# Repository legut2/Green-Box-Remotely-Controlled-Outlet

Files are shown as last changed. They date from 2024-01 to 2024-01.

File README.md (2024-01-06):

# Green Box: Remotely Controlled Outlet(s) to Reduce Electricity Consumption and Monitor Equipment
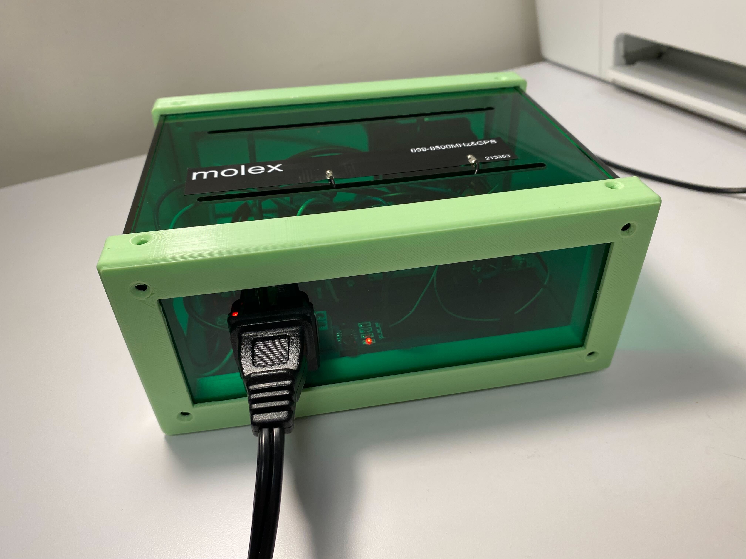
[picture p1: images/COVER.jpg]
cover photo of greenbox Green Box

# Intro
In a world where customers and investors increasingly support environmentally friendly products and services, distinguishing a genuine eco-conscious company from greenwashers is challenging. Many organizations strive to be recognized for their minimal environmental impact, with some genuinely caring for the environment. The greenbox concept caters to these environmentally conscious companies. It's crucial to acknowledge that people often forget to turn off devices, leading to unnecessary energy consumption. Most companies depend on well-trained employees to remember to switch off equipment, a method that lacks sustainability and transparency.  '
  
Personally, I often joke that I'm a one-man ecological disaster due to my environmentally harmful habits, such as not recycling and using disposable plates and cups excessively. Despite this, I consider myself environmentally aware. My individual environmental footprint may be small, but my professional decisions can significantly impact the environment. To compensate for my subpar personal environmental practices, I propose an idea to help companies reduce power consumption. This involves remotely monitoring and deactivating outlets that consume power unnecessarily, a step towards more responsible energy use in the workplace.

# Materials and Supplies
- [Blues Global Starter Kit](https://shop.blues.com/products/blues-global-starter-kit)
- [One Channel 5V Relay](https://www.amazon.com/gp/product/B00LW15A4W/ref=ox_sc_saved_title_2?smid=A30QSGOJR8LMXA&psc=1)
- [Wired Outlet Plug](https://www.amazon.com/gp/product/B092VQNKN7/ref=ox_sc_saved_image_3?smid=AOTJB6UAIIPDH&psc=1)
- [Fused Power Socket with Rocker Switch](https://www.amazon.com/gp/product/B07Y8DBF7T/ref=ox_sc_saved_title_6?smid=A1ZS0R4YE7AG81&psc=1)
- [AC to DC 5V Power Supply](https://www.amazon.com/gp/product/B07V5XP92F/ref=ppx_yo_dt_b_search_asin_title?ie=UTF8&psc=1)
- [Power Cord](https://www.amazon.com/gp/product/B000067SLV/ref=ox_sc_saved_title_4?smid=ATVPDKIKX0DER&psc=1)
- [ACS712 Current Sensor](https://www.amazon.com/gp/product/B00XT0PL20/ref=ox_sc_saved_title_7?smid=A30Y6WWS77DGEW&th=1)
- [1/8 inch (3mm) Acrylic 5 Sheets](https://www.amazon.com/gp/product/B0BN17KVV5/ref=ppx_yo_dt_b_search_asin_title?ie=UTF8&th=1)
- 3D Printing Filament PLA
- [wires](https://www.amazon.com/gp/product/B089CXJPSC/ref=ppx_yo_dt_b_search_asin_title?ie=UTF8&th=1), [wires](https://www.amazon.com/gp/product/B089D13Y1N/ref=ppx_yo_dt_b_search_asin_title?ie=UTF8&th=1), [wires](https://www.amazon.com/gp/product/B083352WFF/ref=ppx_yo_dt_b_search_asin_title?ie=UTF8&psc=1), and more [wires](https://www.amazon.com/gp/product/B07GD2BWPY/ref=ppx_yo_dt_b_search_asin_title?ie=UTF8&th=1)
- [Soldering Flux](https://www.amazon.com/gp/product/B008ZIV85A/ref=ppx_yo_dt_b_search_asin_title?ie=UTF8&th=1)
- [M3 Nylon Fasteners](https://www.amazon.com/gp/product/B076J5RGKS/ref=ppx_yo_dt_b_search_asin_title?ie=UTF8&th=1), [M3 Nylon Standoffs](https://www.amazon.com/gp/product/B0B2MPSH6T/ref=ppx_yo_dt_b_search_asin_title?ie=UTF8&th=1), and more [M3 Nylon Fasteners](https://www.amazon.com/gp/product/B071XPTK7Z/ref=ppx_yo_dt_b_search_asin_title?ie=UTF8&psc=1) because Nylon doesn't conduct electricity well at all.
- [Super Glue](https://www.amazon.com/Starbond-Cyanoacrylate-Microtips-Woodturning-Stabilizing/dp/B00C32ME6G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)
- [USB-A to Micro USB type B](https://www.amazon.com/Amazon-Basics-Charging-Transfer-Gold-Plated/dp/B0711PVX6Z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) to flash board
- [Cotton balls](https://www.amazon.com/Amazon-Basics-Cotton-Balls-200ct/dp/B09497R2CN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) for cleaning burn marks on cut panels
- [Cotton Swabs](https://www.amazon.com/Amazon-Basics-Cotton-Swabs-500ct/dp/B09541P9WH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) for cleaning burn marks on cut panels
- [Rubbing Alcohol](https://www.amazon.com/Amazon-Brand-Rubbing-Alcohol-Antiseptic/dp/B07RB7XYQ1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) for cleaning tooling marks
# Tools
- [Helping Hands](https://www.amazon.com/gp/product/B08R5CDSX4/ref=ppx_yo_dt_b_search_asin_title?ie=UTF8&psc=1) for holding wires and parts while soldering
- [Wire Strippers](https://www.amazon.com/gp/product/B000JNNWQ2/ref=ppx_yo_dt_b_search_asin_title?ie=UTF8&th=1)
- [Wire Wrap Tool](https://www.amazon.com/gp/product/B00C9NWR1Q/ref=ppx_yo_dt_b_search_asin_title?ie=UTF8&psc=1) for a quick way to alternatively attach wires
- [Portable Soldering Iron](https://www.amazon.com/gp/product/B071K5FNGT/ref=ppx_yo_dt_b_search_asin_title?ie=UTF8&th=1)
- [Dremel 3D40 Printer](https://fox.build/equipment/dremel-3d40-printer/)
- [Laser Cutter](https://fox.build/equipment/big-blue-laser/)
- [X-ACTO Knife](https://www.amazon.com/X-ACTO-Yourself-Great-Arts-Crafts/dp/B000HGMA7I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) and/or [Clay Shaping Tools](https://www.amazon.com/TEACHERS-Pottery-Sculpting-Double-Sided-Handles/dp/B08KD22B4Y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) for cleaning up 3D print
# Software Tools
- [Arduino](https://www.arduino.cc/en/software)
- [VSCode](https://code.visualstudio.com/)
- [Notehub](https://notehub.io)
- [Python 3.10.0](https://www.python.org/downloads/release/python-3100/)
# Schematic
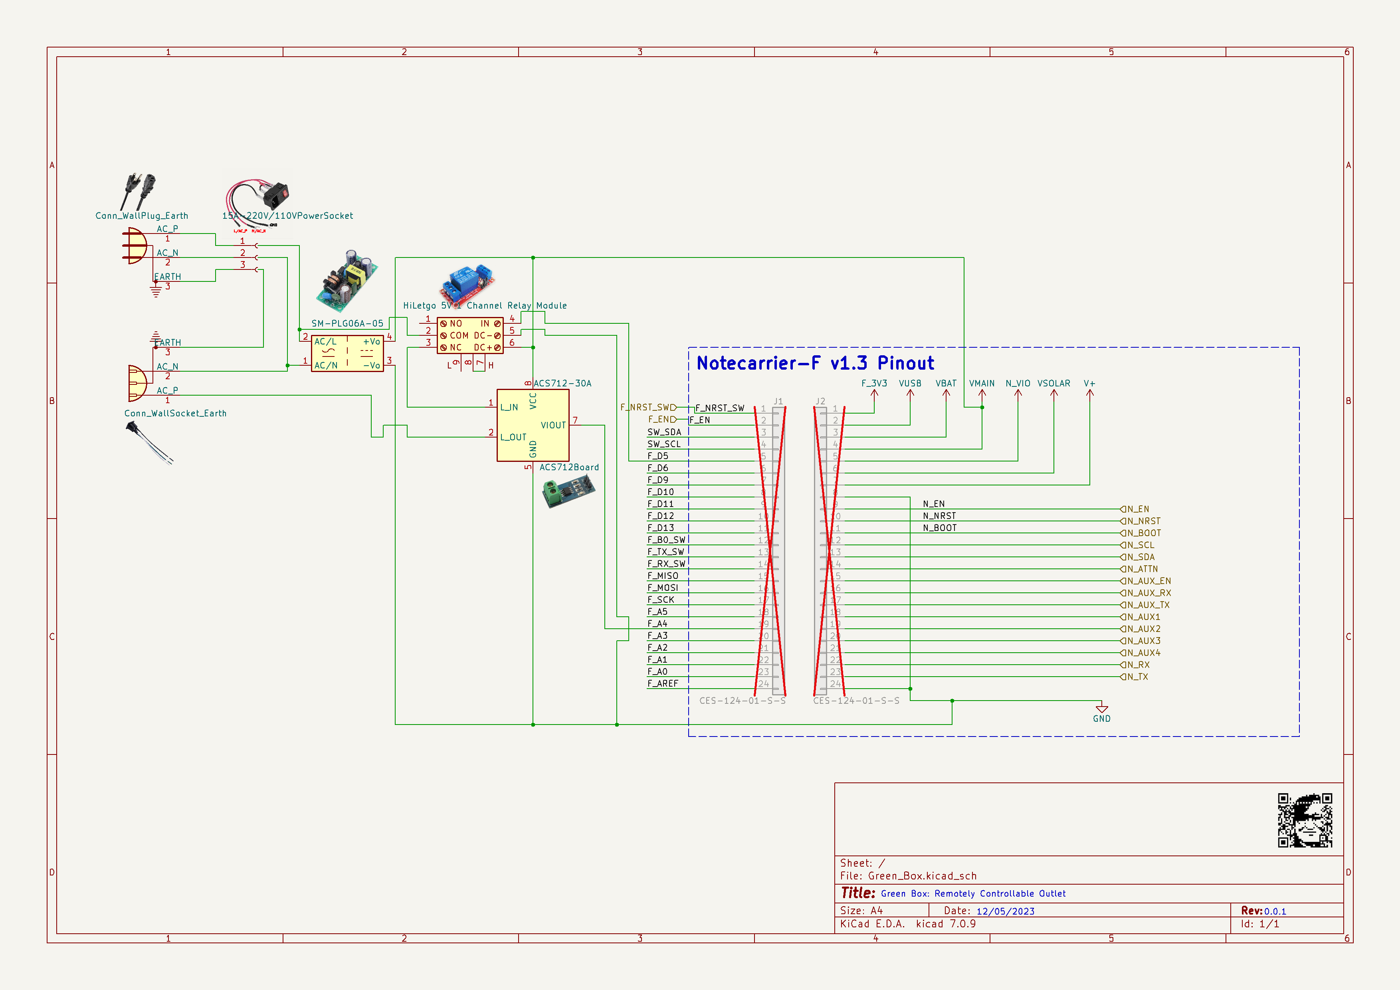
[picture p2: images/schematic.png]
schematic of greenbox Schematic
  
[KiCAD Zipped Files](./Green_Box_KiCAD.zip)  
# CAD
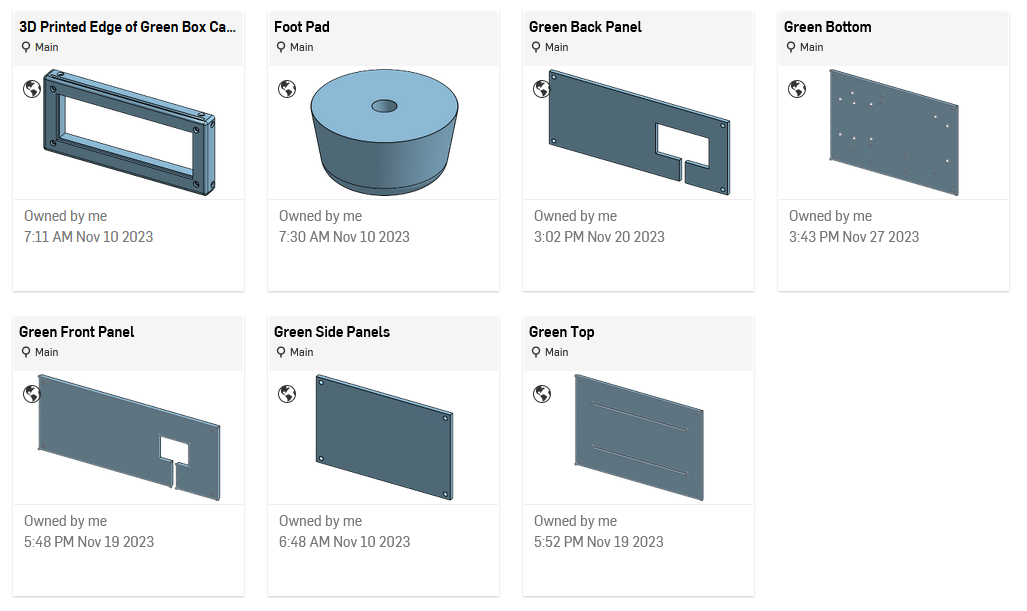
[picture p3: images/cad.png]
CAD Models of Box Parts

- [3D Printed Edges](https://cad.onshape.com/documents/768bf325ce61f204b1c20e3a/w/13f10a06ca5bd000585b50f8/e/0a809bd2397b4e0a646dd88c) [(STL File)](./CAD/3D%20Printed%20Edge.stl)
- [Bottom Panel](https://cad.onshape.com/documents/b0d329d86337c70760adce23/w/ca1183aaf425e30395dbaaf4/e/549da84961c1aeb2ba495f54) [(DXF File)](./CAD/Green%20Bottom.dxf)
- [Front Panel](https://cad.onshape.com/documents/e55aef7daf51d2362b13b44b/w/da2b1076433f546c797e1f83/e/66cb452b38848d0268798330) [(DXF File)](./CAD/Front%20Panel.dxf)
- [Back Panel](https://cad.onshape.com/documents/593eb36193b087ff43dc2f72/w/bbb9e1fdf7dfe1317e187362/e/3f4225e0dbdc0654de7b20f0) [(DXF File)](./CAD/Back%20Panel.dxf)
- [Side Panel](https://cad.onshape.com/documents/a36065bf40c209600cc4383d/w/08a4eee43424d48ec8693589/e/5a183de64443f7edcd656746) [(DXF File)](./CAD/Side%20Panel.dxf)
- [Top Panel](https://cad.onshape.com/documents/84086fb6dc831c0922238dac/w/1929451043a0cdd72cf4c331/e/d913d1e3925c53207bd2e979) [(DXF File)](./CAD/Top%20Panel.dxf)
- [Foot Pad](https://cad.onshape.com/documents/e05155efe7ebecf075a4ab0f/w/05d481c3344dacce6687c214/e/0d07fca45d25f3ce5d8b2458) [(STL File)](./CAD/Foot%20Pad.stl)
# Guide
### Start with Printing Edges and Cutting Panels
For me, it's really frustrating when hardware moves around and isn't secure. It makes troubleshooting much more difficult if electronics are moving and aren't mounted firmly in place. So we're going to start by 3D printing the edges and laser cutting the panels. So open whatever compatible slicer software you have and prepare your print file for printing. Please know that the image below is representative and isn't ultimately the print file I ended up using.
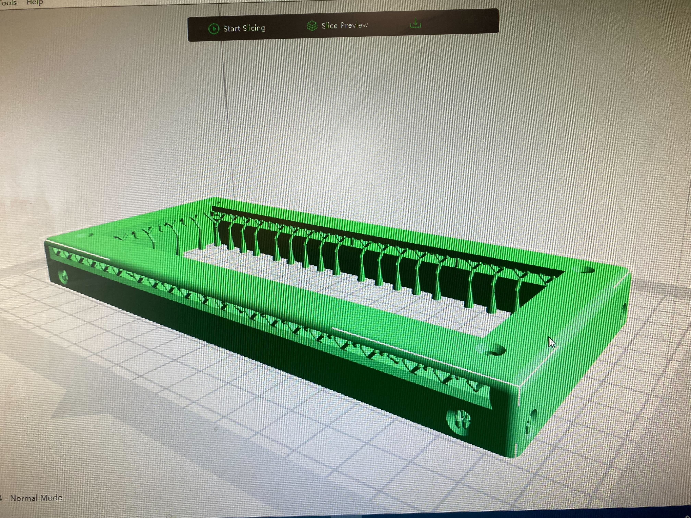
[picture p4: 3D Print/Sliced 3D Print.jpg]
3D model

Here you can find the [3D Print gcode I used](./3D%20Print/Green%20Box%20Enclosure%20Edge.gcode), but results may vary because you may have a different printer than the one I used. However, looking at the supports I used may be very useful. It took quite a lot of trial and error to get the supports right, and you want to avoid any layer shifts to have panel fit easily. You'll want to print 2 of these edges.
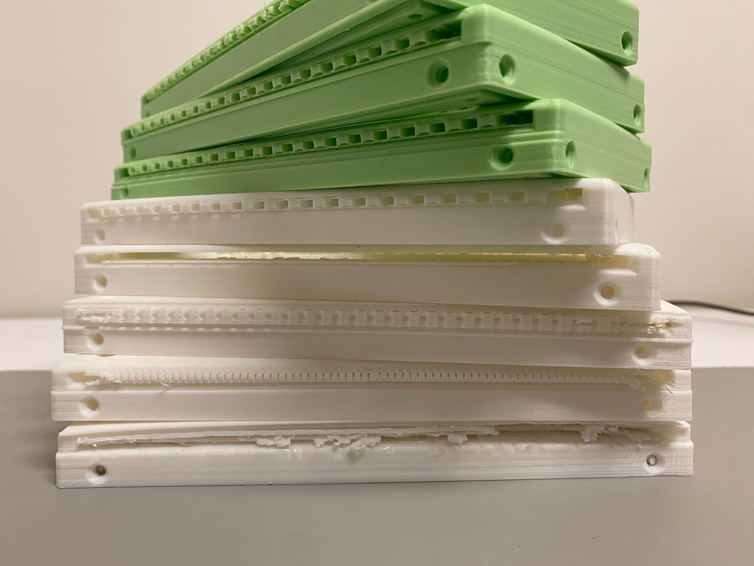
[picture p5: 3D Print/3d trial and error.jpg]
Trial and Error to get supports and layer shifting correct

Next you want to use the dxf files and load them into your laser cutting software and verify correct units within the software. Then utilize 70% power and 5.5mm/s jogging speed to cut the acrylic panels. Depending on how much wear and the wattage of the laser you use, you may have to use different settings used to cut through the acrylic sheets. Cut out the bottom, 2 sides, top, front, and back panel. Given the tedious nature of 3D printing, it is really nice to be able to laser cut parts for any design changes. This is especially true for prototyping. There is time saved on small changes where you don't have to wait as long for a machine to run to make you a part.
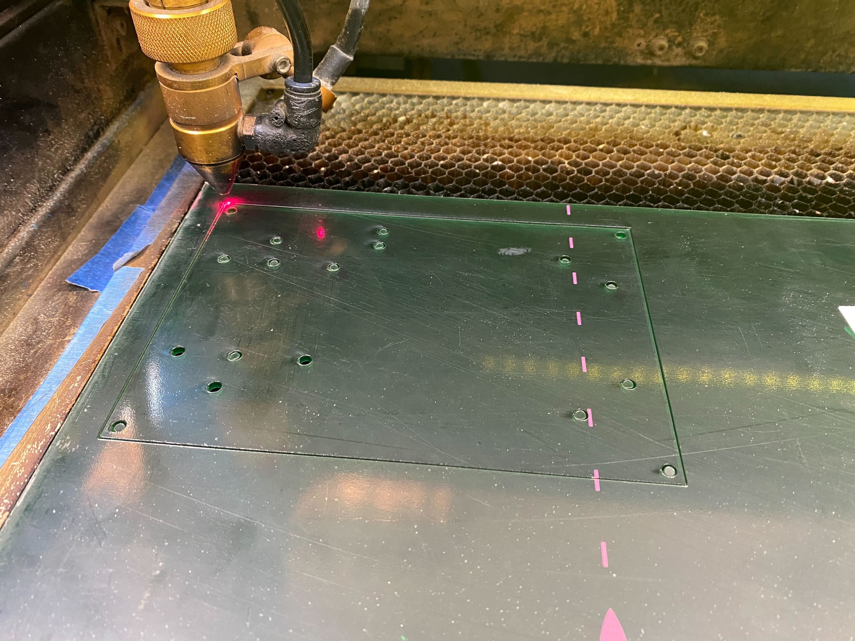
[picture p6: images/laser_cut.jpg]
Laser Cutting Bottom Panel

Next you'll notice there are burn marks left over from the laser cutting through.
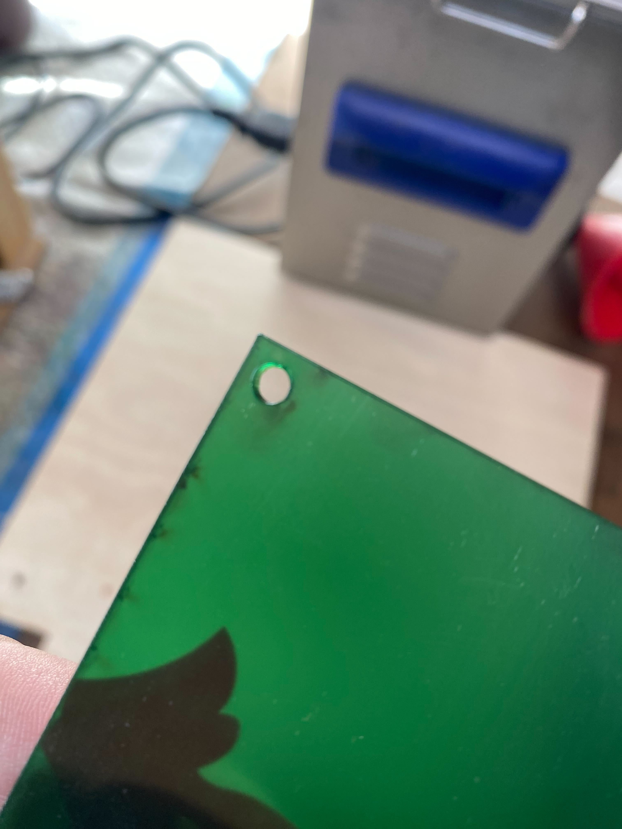
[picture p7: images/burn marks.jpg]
Tooling Marks from Laser Cutter

You'll want to use rubbing alcohol to clean that up.
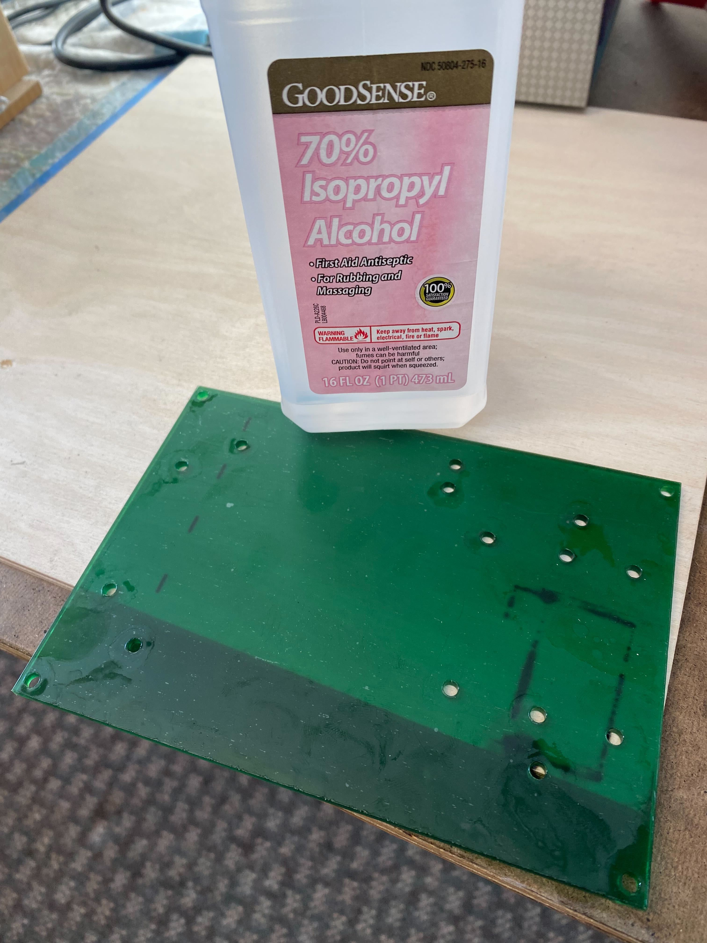
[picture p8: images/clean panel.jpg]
Rubbing Alcohol

That's much better!
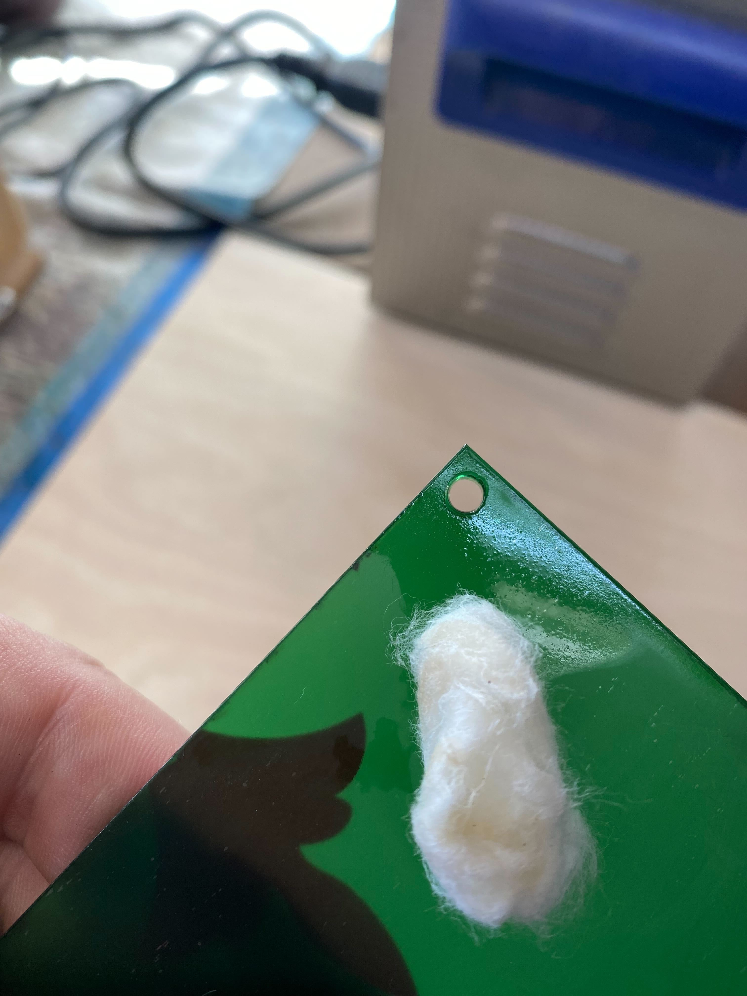
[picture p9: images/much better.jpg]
Cleaned up edges of each panel

Also, you'll want to spend time using an X-ACTO knife and other sharp tools, like from a clay sculpting kit to clean off any supports from your 3D prints.
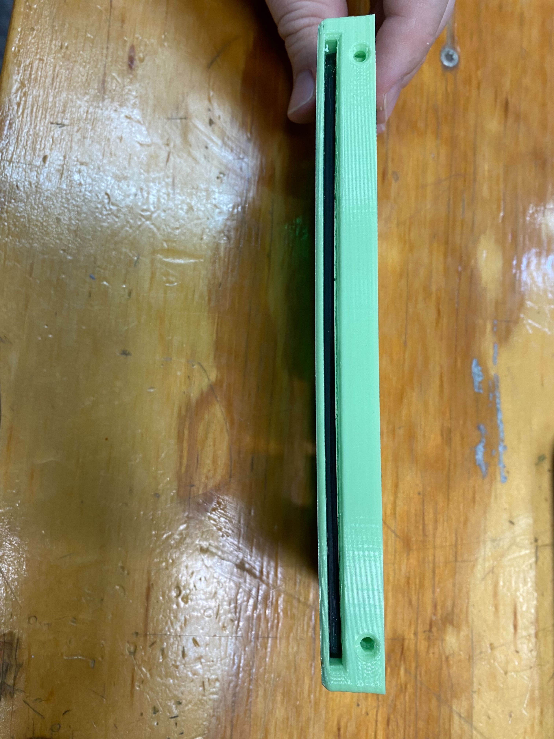
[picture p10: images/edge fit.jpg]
Cleaned up 3D Print

The edge should be able to cleanly fit one of the front of back panels, and use them to gauge how cleaned up the edge parts are for the box.
### Test Fit Panels and Edges
Next you'll want to test fit parts together to make sure they all go together nicely.
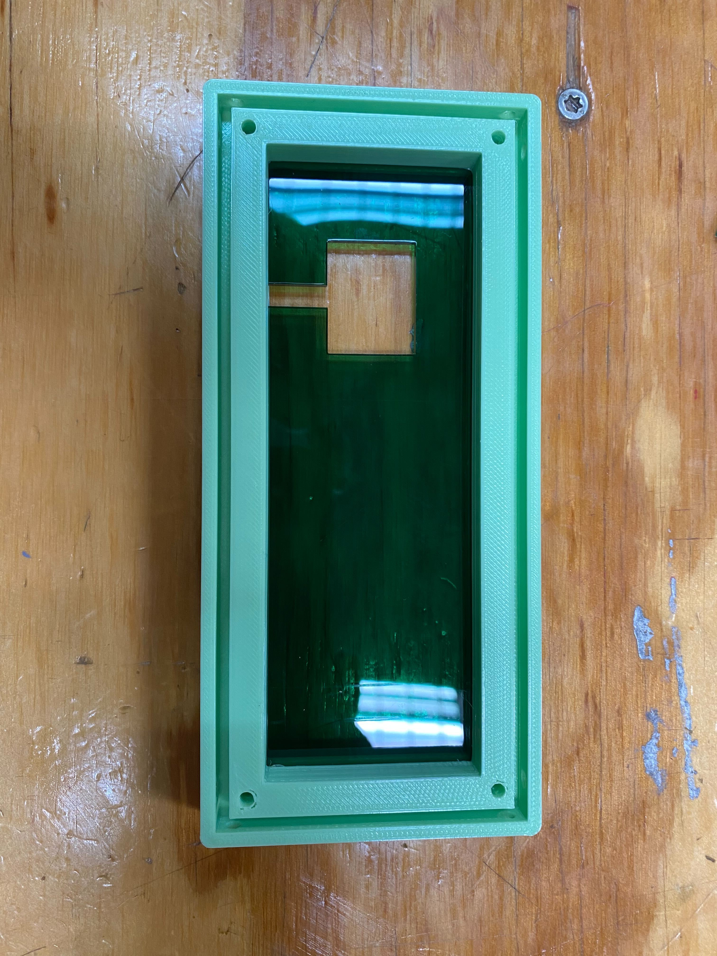
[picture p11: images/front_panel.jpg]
front panel and edge piece put together

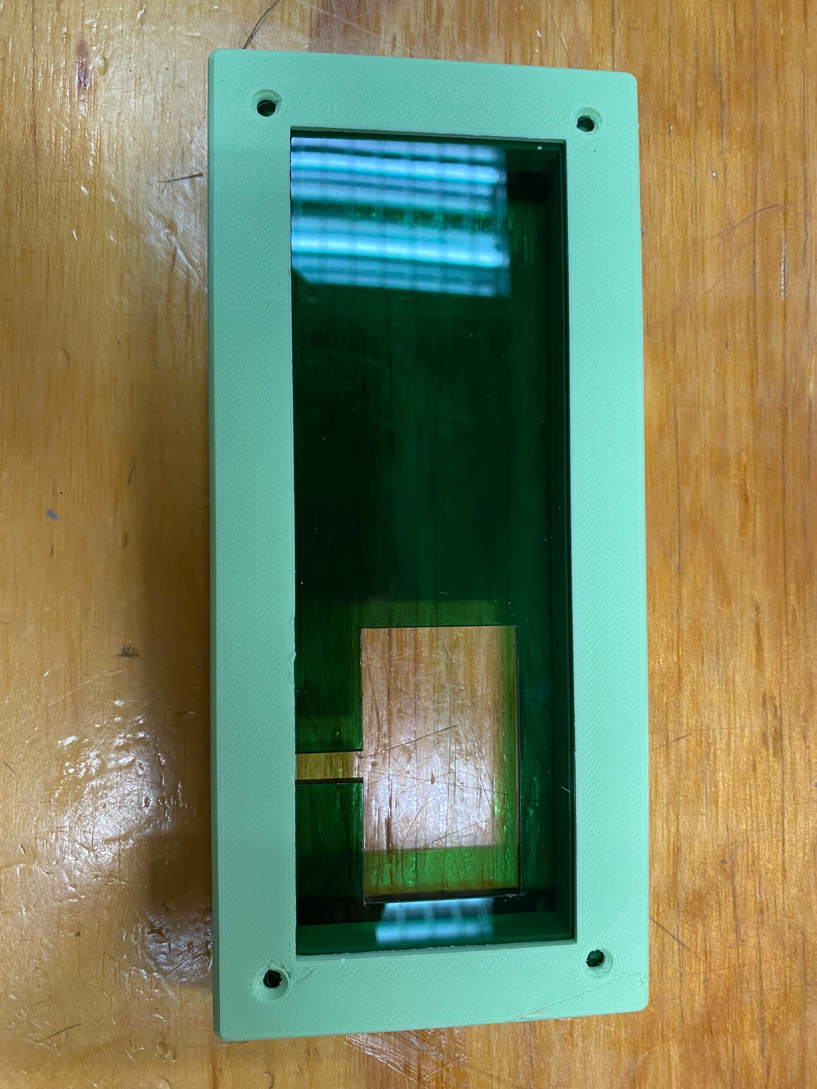
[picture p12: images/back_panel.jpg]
back panel and edge piece put together

Now you will want to make verify that the front plug fits correctly.
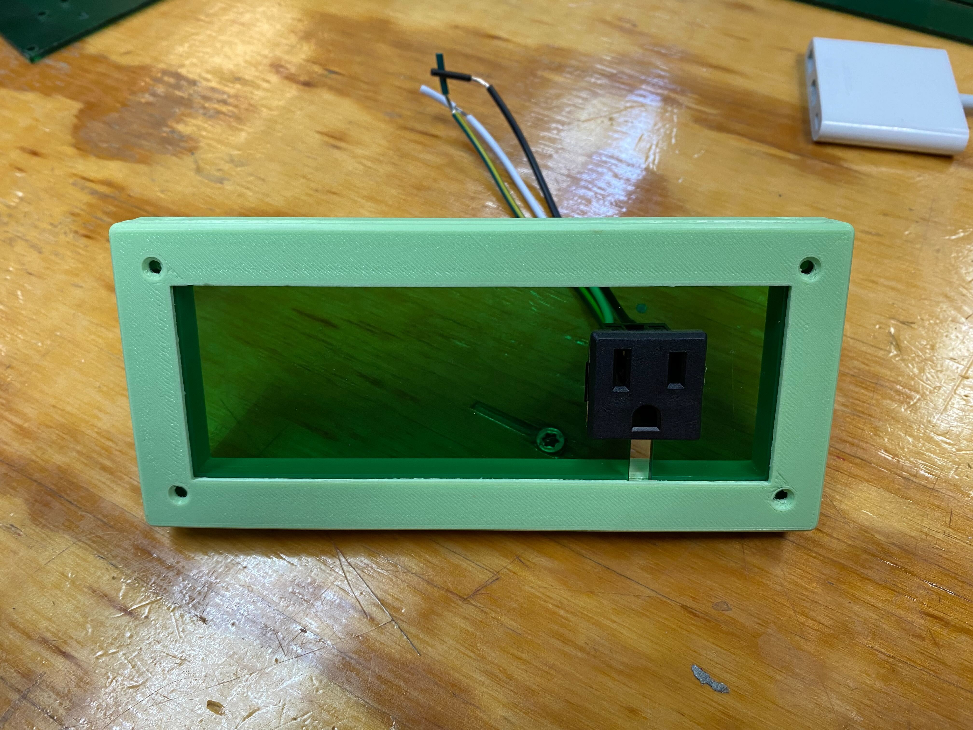
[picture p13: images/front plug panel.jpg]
front plug test fitted into panel

You will want to trim the tabs on the fused power socket to make sure they fit and snap into place.
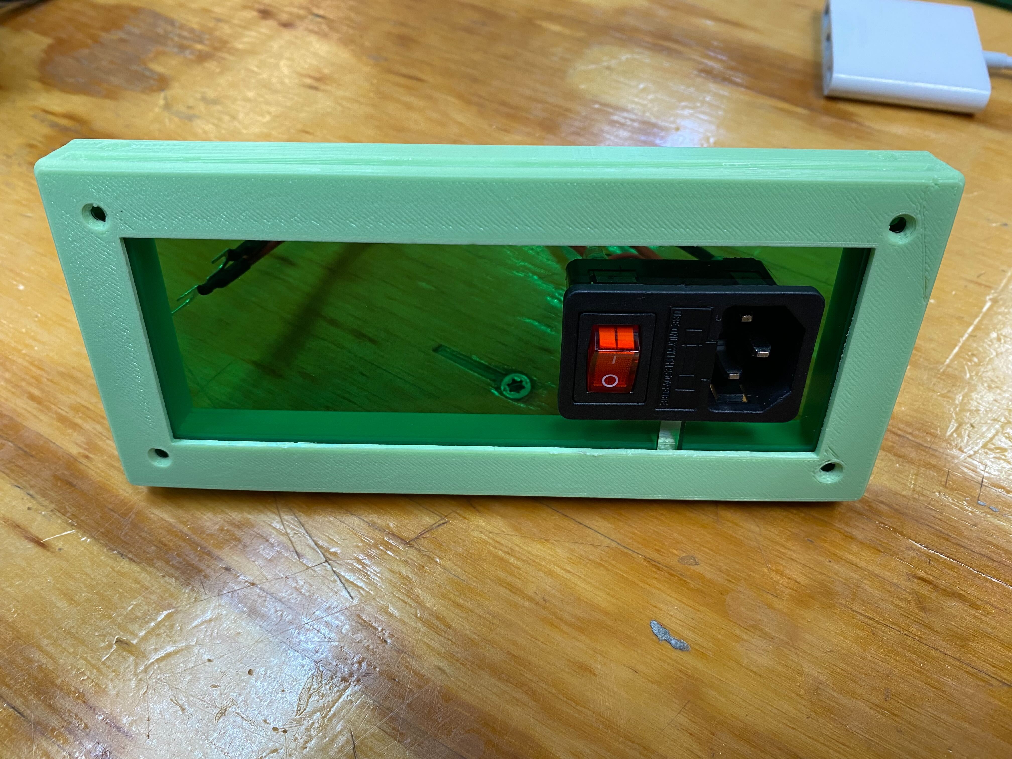
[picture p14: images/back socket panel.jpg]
back socket panel test fit

Now you'll want to make sure panels fit together snuggly like the bottom, sides, and top slide easily together and apart.
### Mount Electronics
Now mount the blues wireless board by using M3 standoffs and M3 fasteners together onto the bottom panel. One of the benefits, that isn’t immediately obvious, is that this board has a dedicated data service that comes with it. This is really useful when you realize how many customer calls this can avoid troubleshooting connectivity problems. A surprisingly good number of IT departments are weary of the IoT devices that get setup within the workplace. If we are to hope for any widespread adoption of such a concept, it’s best for it to be on a separate network to make it easy for IT departments to approve it for use.
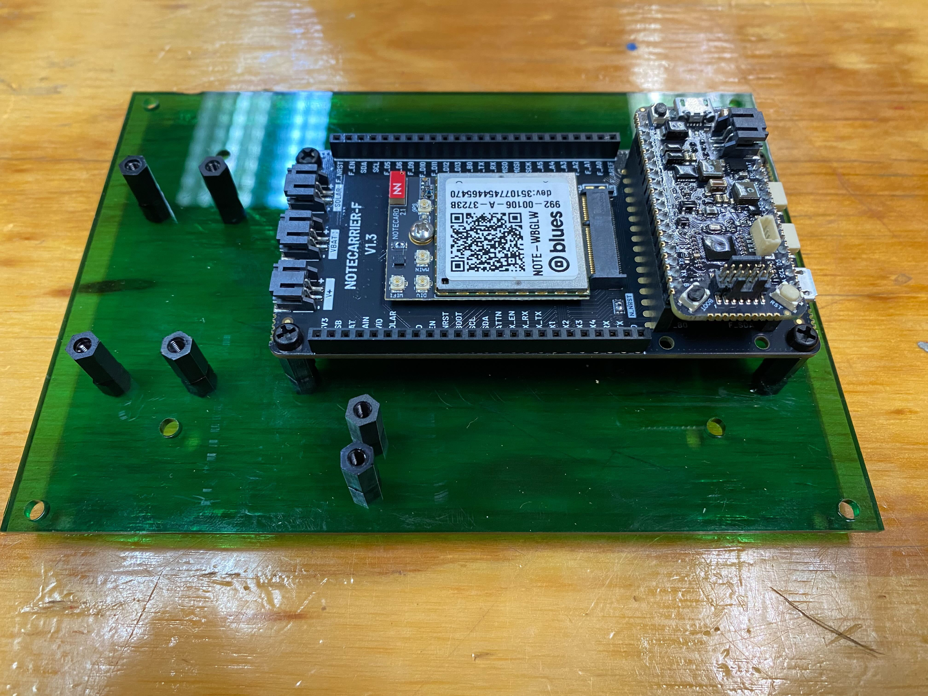
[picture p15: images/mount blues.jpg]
mount blues board

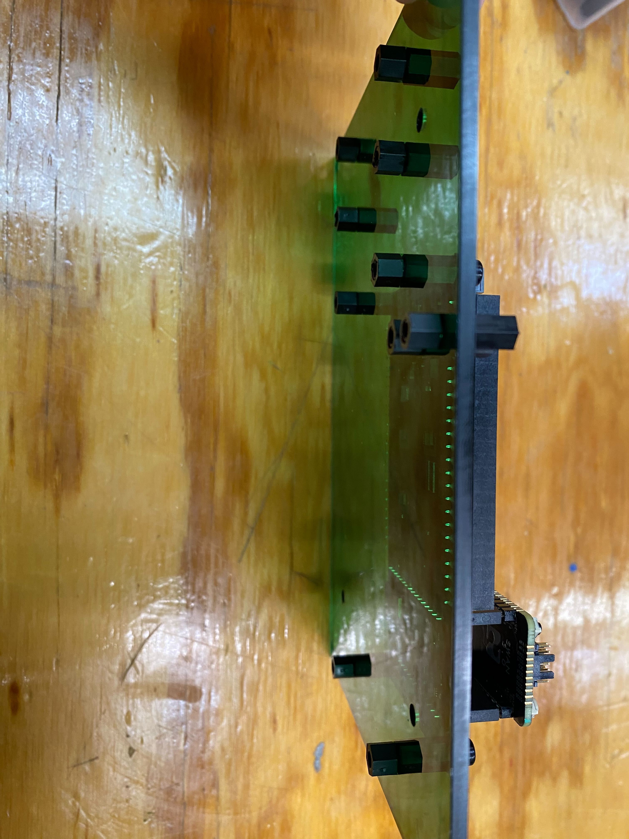
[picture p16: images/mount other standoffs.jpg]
mount standoffs for other parts too

Mount the relay, ACS712 current sensor, and the AC to DC power supply.
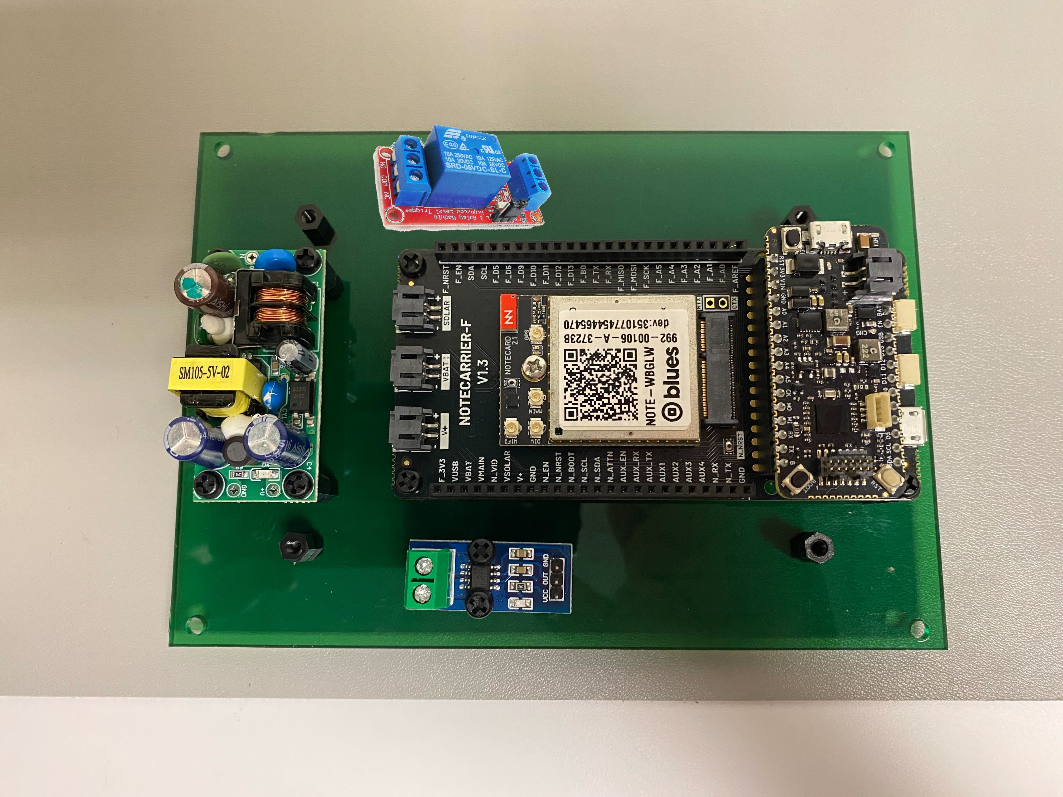
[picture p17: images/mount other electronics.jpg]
mount other electronics

At this point I decided to permanently glue the bottom panel to each edge using super glue, but that is a somewhat irreversible decision. You can also choose to temporarily fasten the bottom panel together. I just kept sliding panels in and out of place by flexing the bottom panel slightly. However, this might not work for everyone because if you use too much force you can crack the bottom panel. So I recommend most people use fasteners.

This clamshell configuration of the case is immensely useful for easily soldering and being able to reach hands into the case from the sides.
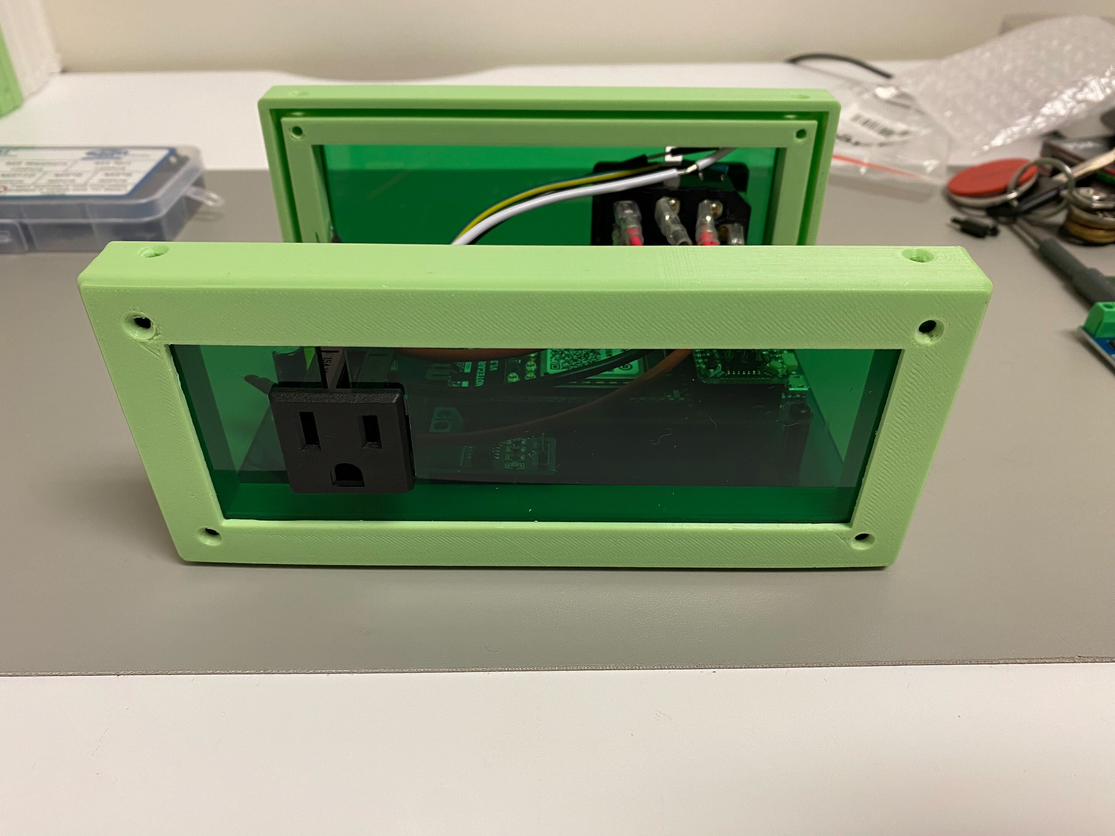
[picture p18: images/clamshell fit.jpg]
clamshell fit of the box

### Wire Electronics together
Solder the electronics together according to the schematic, starting with the internal components that are mounted and working your way outward to the plug and socket on the front and back panel.
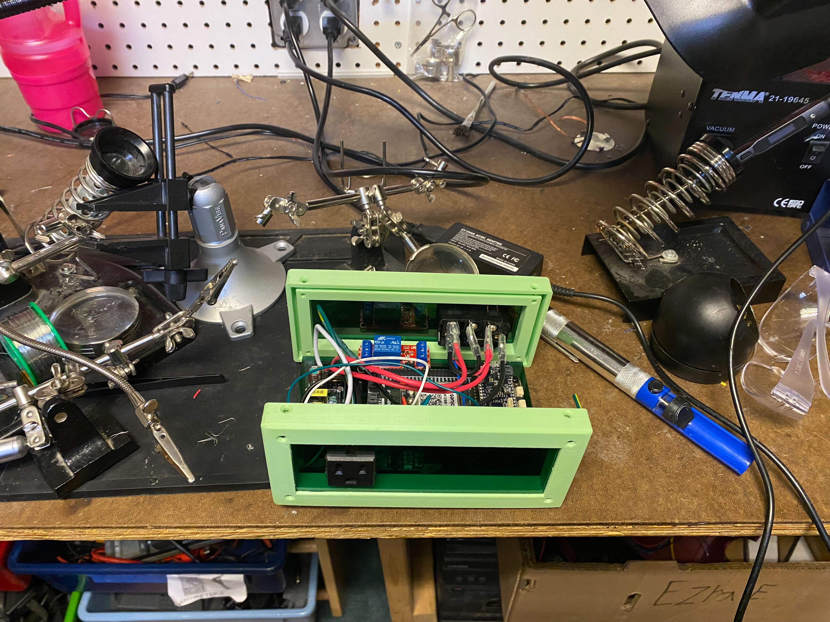
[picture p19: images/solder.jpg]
solder electronics together

It would probably be best to download the [KiCAD schematic](./Green_Box_KiCAD.zip) and be able to zoom in and out on the wiring. In hindsight, I'd recommend desoldering the headers on the blues wireless board for a more secure connection. I had to resort to using jumper wires and wirewrapping some of the ends to make some of the connections.
You'll also want to carefully add the antenna once you're certain of the wiring.
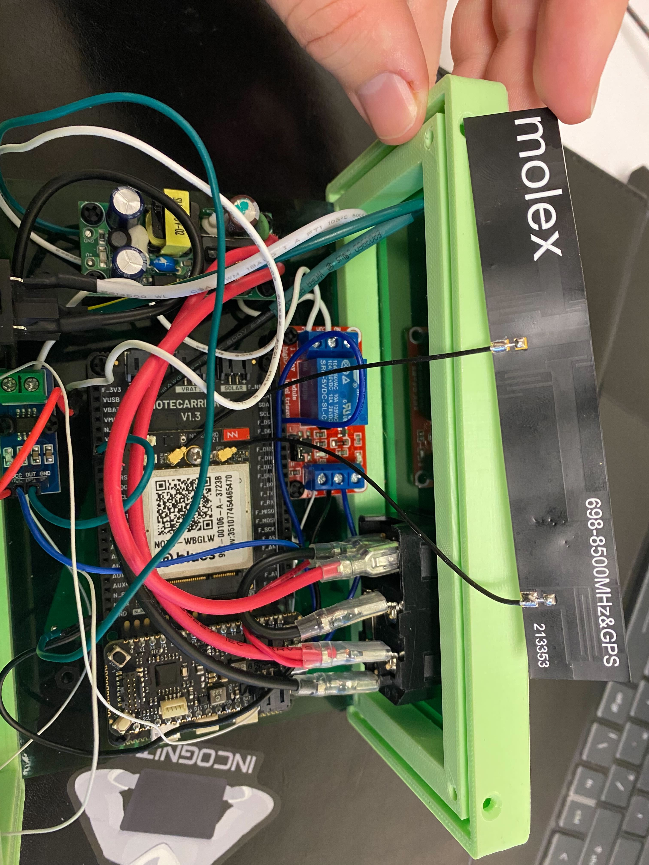
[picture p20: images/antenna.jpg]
antenna plugged in

At the end, you'll want to pop out the socket in the back panel and plug in the usb cord like below to be able to flash software.
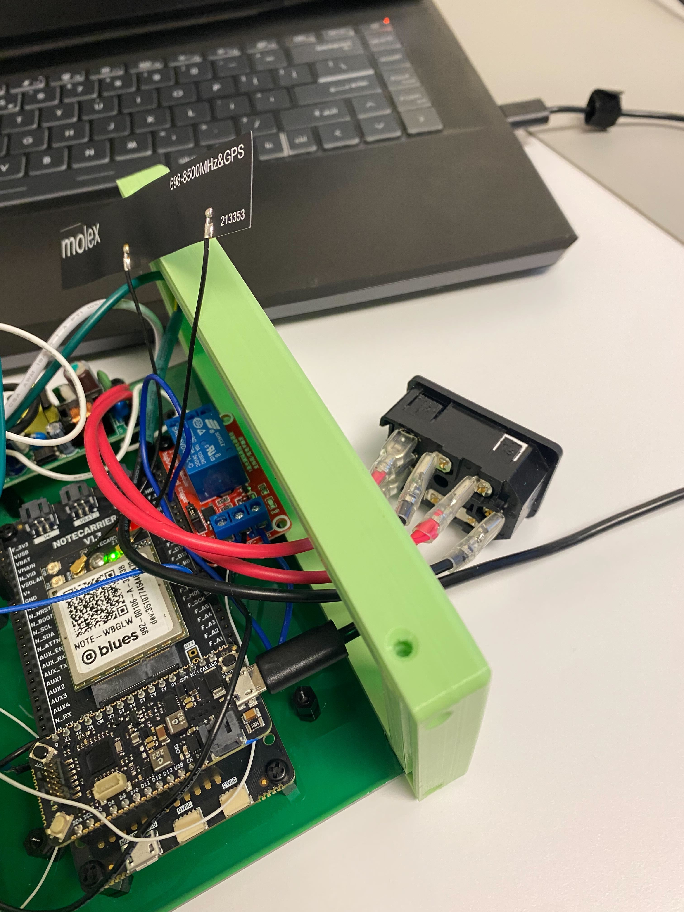
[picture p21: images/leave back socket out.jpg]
leave the back socket out and plug in the usb cord

Now we're ready to move onto the software!
### Programming the Green Box with Arduino IDE
Copy or `git clone https://github.com/legut2/Green-Box-Remotely-Controlled-Outlet.git` the code folder into your Arduino folder, and also open the same folder up with VSCode. The path for me at the end is:

`C:\Users\daniel\OneDrive\Documents\Arduino\Green-Box-Remotely-Controlled-Outlet-main`

We'll be using the Arduino IDE and you will want to reference [the following guide](https://dev.blues.io/swan/using-arduino-ide-with-swan/) to setup your Arduino IDE. I mostly did all the same setup but used the 'Blues Wireless Boards' board after importing the board manager file: `https://github.com/stm32duino/BoardManagerFiles/raw/main/package_stmicroelectronics_index.json`
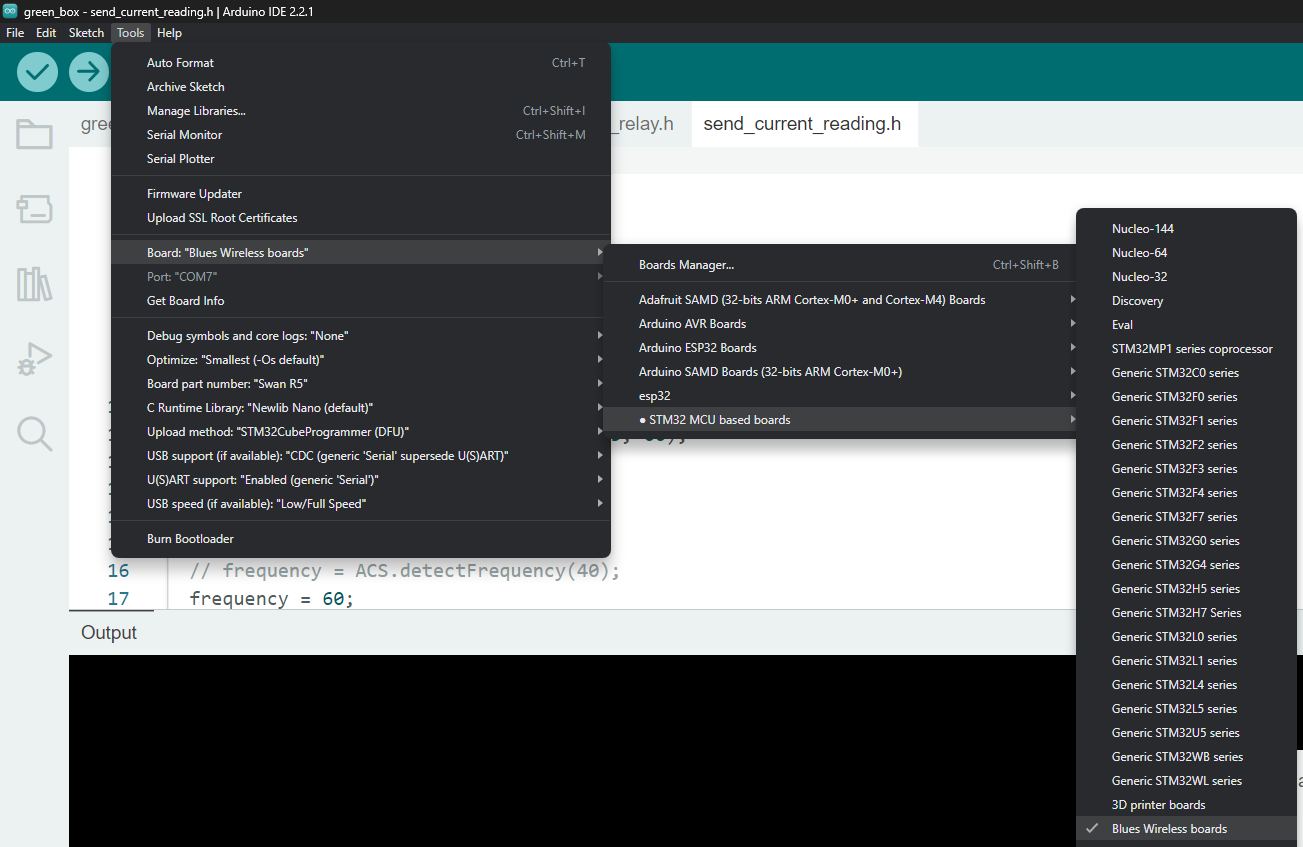
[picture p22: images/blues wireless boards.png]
Blues Wireless boards selected as board


Install the following libraries from the library manager within Arduino: [Blues Wireless Notecard by Blues](https://github.com/blues/note-arduino), [Blues Wireless Notecard Pseudo Sensor by Blues Wireless](https://github.com/blues/notecard-pseudo-sensor), and [ACS712 by Rob Tillaart, and Pete Thompson](https://github.com/RobTillaart/ACS712)

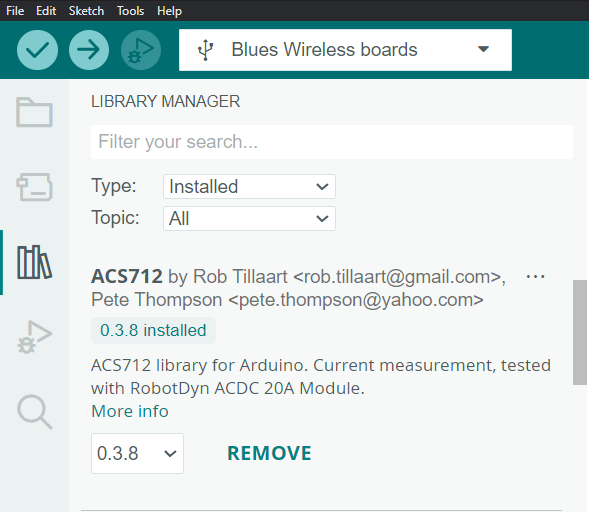
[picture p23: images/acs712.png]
acs712 library


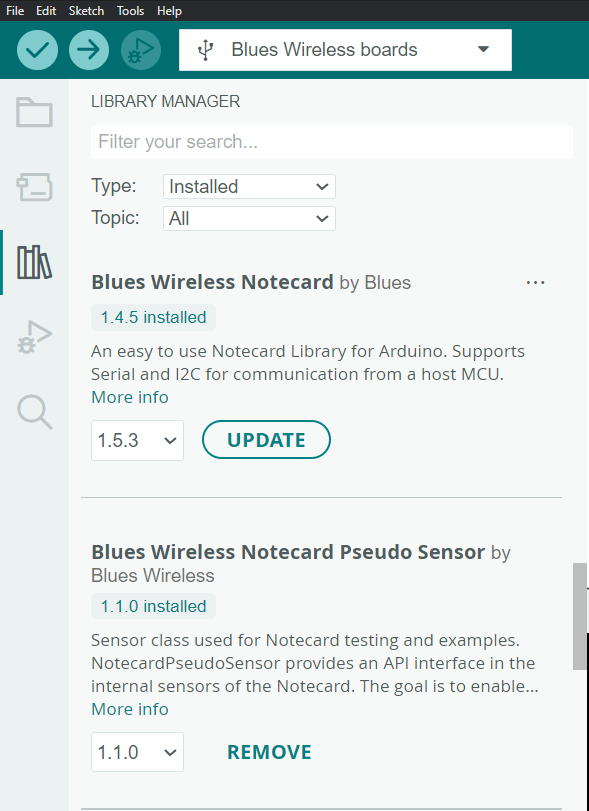
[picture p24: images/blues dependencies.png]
blues dependencies


Create a notehub.io account, create a project, and copy the product UID:

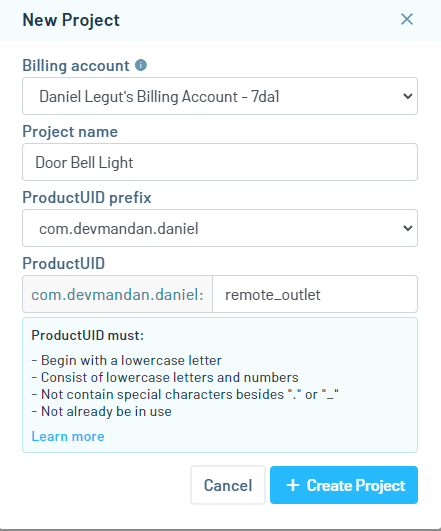
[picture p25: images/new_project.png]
new project


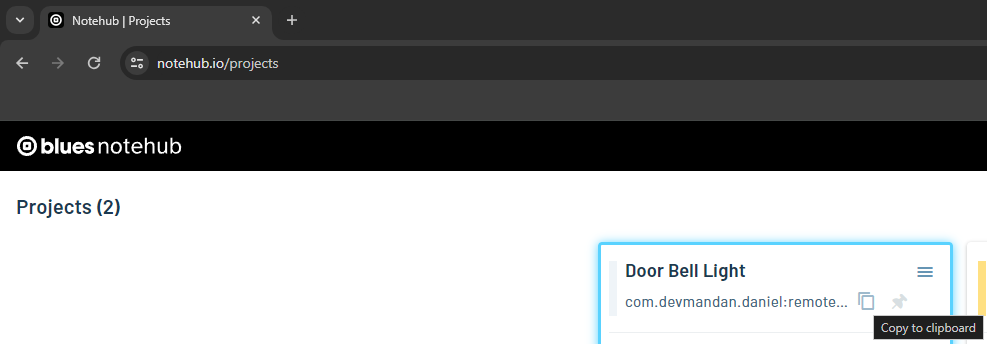
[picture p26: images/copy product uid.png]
copy product uid


Replace the existing `productUID` at the top of `green_box.ino`:

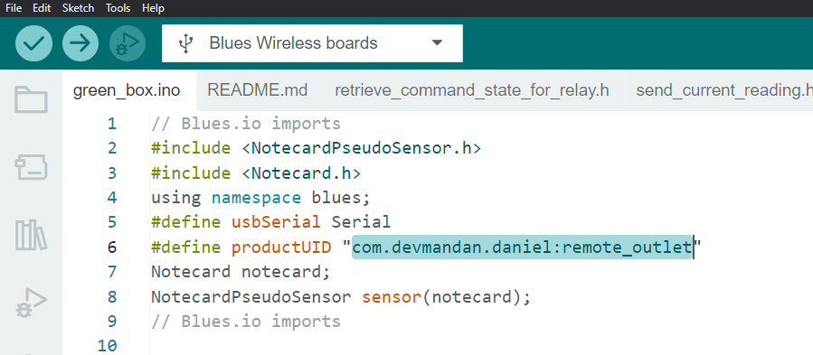
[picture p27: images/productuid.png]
product uid within green_box.ino file


Whenever flashing the board, it's important to keep in mind that you'll have to do the following sequence after hitting upload each time: 

```Press and hold the BOOT button on the Swan, press and release RESET, then release BOOT to cause the Swan to jump into its bootloader. This sequence must be done every time you want to upload firmware to the Swan.```

Now go ahead and flash the board! Now measurements of current are being sent to notehub.io!

![sending data diagram](./images/send%20data.png)

You should be able to see data recorded under events within your notehub.io dashboard now. This will allow you send current sensor readings to be recorded.

### VS Code: using a python client to turn the outlet on and off remotely!
Time to send the box commands and remotely control the outlet through a python client that naively sends the desired relay state over and over again.

![greenbox receiving commands diagram](./images/receive%20commands.png)

Make sure to have python 3.10 installed. Now open up VS Code and we'll go ahead and update the .env file with the appropriate credentials so we can send commands through notehub.io. You can find the `.env_example` file within the `send_command` folder. The python script `send_command.py` automatically sources/loads a `.env`. However, you need to change the `.env_example` to be named `.env`. As best practice, it's wise not to commit this file to github or any kind of version control software.

#### Create `CLIENT_ID` and `CLIENT_SECRET` within notehub.io
Navigate to your dashboard and click on settings.  

![settings way one](./images/settings1.png)
![setttings way two](./images/settings2.png)

Now go ahead and scroll down through your and click on `Generate programatic access`, copy the credentials into `.env`, and click save within the settings!

![generate credentials](./images/generate%20programmatic%20access.png)

#### Find `PROJECT_ID` and `DEVICE_ID`

Scroll all the way back up and copy over the `Project UID` without the `app:` over to your `.env` file for `PROJECT_ID`. You can also see this as part of the URL within your web browser's address bar.

![copy Project UID](./images/project%20id%20at%20top%20of%20settings.png)

Lastly, click onto `Devices` and copy over the relevant ID under the `Best ID` column for `DEVICE_ID` within the `.env` file.

![copy the device ID from Devices page](./images/device%20id.png)

#### Run `send_command.py`
Create a virtual environment for your dependencies:  

`python -m venv .venv`  

To activate:
#### windows  
`.\.venv\Scripts\activate`
#### linux/mac
`source .venv/bin/activate`

Install dependencies:  
`pip install -r requirements.txt`

Run the client:
`python send_command.py`

Type `True` or `False` and wait 20-30 seconds and the Green Box should update to that state. You can troubleshoot by looking at the events tab within `notehub.io` and looking at the serial monitor to see if it is looping through the notes. `False` should open the relay, and `True` should make the relay closed.

![more data events](./images/data_sent.png)

# Success!

![blinking gif example of lamp](./images/blink%20final.gif)

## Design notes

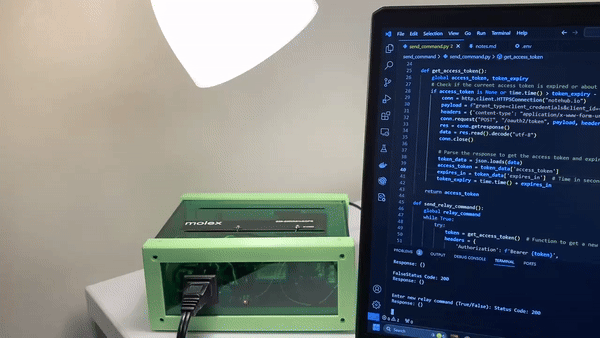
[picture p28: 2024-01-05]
images/blink final.gif

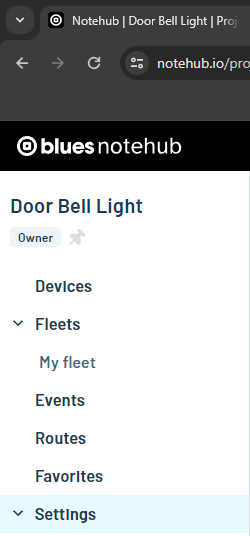
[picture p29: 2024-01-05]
images/settings2.png

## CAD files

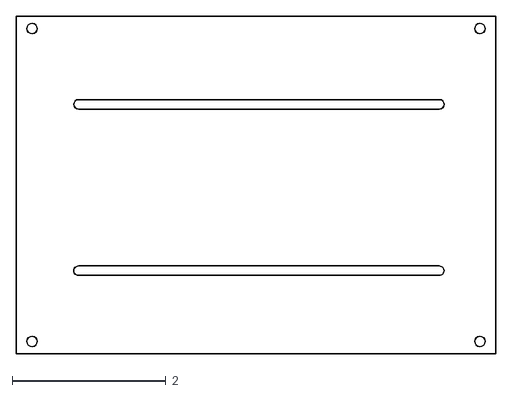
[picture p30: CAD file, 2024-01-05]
CAD/Top Panel.dxf
6.25 x 4.40

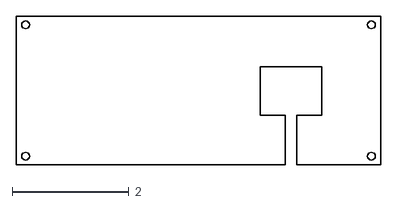
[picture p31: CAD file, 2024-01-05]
CAD/Front Panel.dxf
6.25 x 2.55

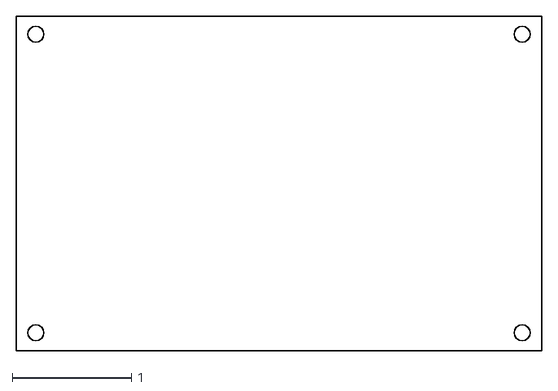
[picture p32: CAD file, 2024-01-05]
CAD/Side Panel.dxf
4.40 x 2.80

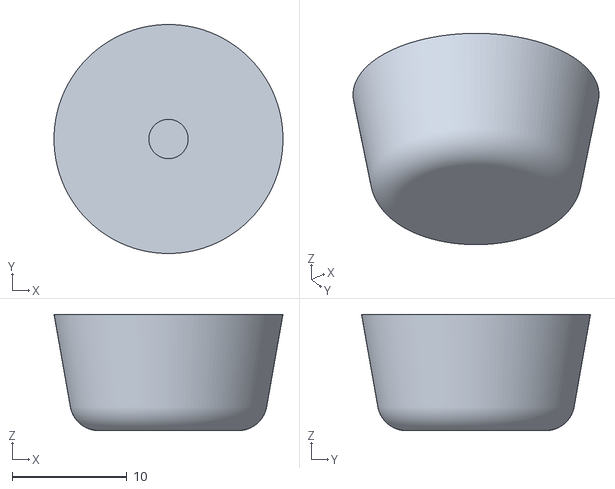
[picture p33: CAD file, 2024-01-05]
CAD/Foot Pad.stl
20.0 x 20.0 x 10.2

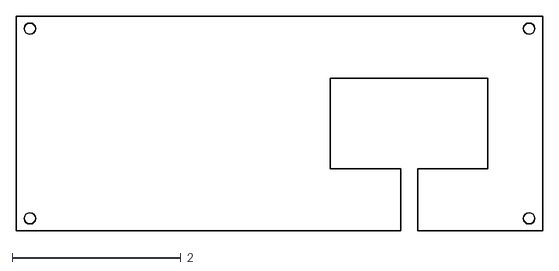
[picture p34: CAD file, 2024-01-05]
CAD/Back Panel.dxf
6.25 x 2.55

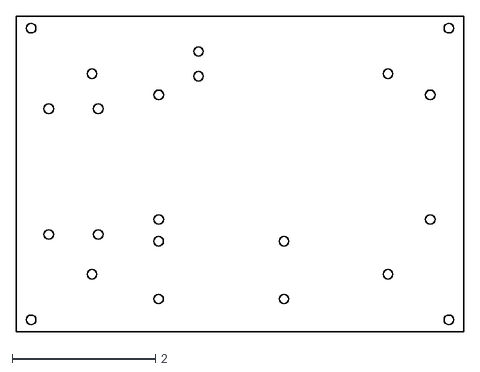
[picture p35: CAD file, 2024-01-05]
CAD/Green Bottom.dxf
6.25 x 4.40

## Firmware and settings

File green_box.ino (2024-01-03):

// Blues.io imports
#include <NotecardPseudoSensor.h>
#include <Notecard.h>
using namespace blues;
#define usbSerial Serial
#define productUID "com.devmandan.daniel:remote_outlet"
Notecard notecard;
NotecardPseudoSensor sensor(notecard);
// Blues.io imports

#include <retrieve_command_state_for_relay.h>
#include <send_current_reading.h>

#include <Arduino.h>

#define DIGITAL_RELAY_CONTROL D5 //pin definition for which pin the relay is soldered to

void blues_setup() {
  notecard.begin();
  notecard.setDebugOutputStream(usbSerial);
  J *req = notecard.newRequest("hub.set");
  JAddStringToObject(req, "product", productUID);
  JAddStringToObject(req, "mode", "continuous");
  JAddBoolToObject(req, "sync", true);
  J *rsp = notecard.requestAndResponse(req);
  
  notecard.deleteResponse(rsp);
}

void relay_setup() {
  //set pin to be an output
  pinMode(DIGITAL_RELAY_CONTROL, OUTPUT);

  //Sends voltage high signal to relay
  digitalWrite(DIGITAL_RELAY_CONTROL, LOW);// set relay pin to HIGH
}

void setup() {
  //tell blues we've booted up and send some data
  blues_setup();

  //setup relay and keep on initially (NC)
  relay_setup();
    
  
  // initialize digital pin LED_BUILTIN as an output, so we know when relay is closed or not
  pinMode(LED_BUILTIN, OUTPUT);
  Serial.begin(115200);
  while (!Serial);
  Serial.println(__FILE__);
  Serial.print("ACS712_LIB_VERSION: ");
  Serial.println(ACS712_LIB_VERSION);

  //setup the ammeter that measures current
  setup_acs712();
}

int mismatch_counter = 0;
bool local_relay_state = true;

std::optional<bool> update_local_relay_state() {
  std::optional<bool> desired_relay_state = check_notes_for_digital_relay_control_command(notecard);
  if (desired_relay_state.has_value()){ 
    bool desired_state = desired_relay_state.value();
    bool state_mismatch = (desired_state != local_relay_state);
    if (state_mismatch) {
      mismatch_counter++;
    }
    if (state_mismatch && mismatch_counter > 2) { //this logic makes relay more reliable in terms of state (on or off) but less responsive overall
      local_relay_state = desired_state;
      mismatch_counter = 0;
    }
  }
  if (local_relay_state) {
    digitalWrite(LED_BUILTIN, HIGH);   // turn the LED off by making the voltage LOW
    digitalWrite(DIGITAL_RELAY_CONTROL, LOW);// //Sends voltage low signal to relay
  } else {
    digitalWrite(LED_BUILTIN, LOW);   // turn the LED off by making the voltage LOW
    digitalWrite(DIGITAL_RELAY_CONTROL, HIGH);// //Sends voltage low signal to relay
  }
  return desired_relay_state;
}

// simple logic of greenbox
void loop() {
  //definition and implementation of read_simple_average_of_current_ma and send_sensor_value_to_blues can be found within send_current_reading.h file
  send_sensor_value_to_blues(read_simple_average_of_current_ma(), notecard);
  //gets desired relay state from blues and checks to see if there is a mismatch to local relay state, if there is and it isn't a fluke - updates relay state
  std::optional<bool> desired_relay_state = update_local_relay_state();
  Serial.print("desired relay state: ");
  if (desired_relay_state.has_value()) {
    Serial.println(desired_relay_state.value() ? "true" : "false");
  } else {
    Serial.println("");
  }
  Serial.print("local relay state: ");
  Serial.println(local_relay_state==1? "true" : "false");
  Serial.print("mismatch counter: ");
  Serial.println(mismatch_counter); # greater than two causes local_relay_state to be changed to desired_relay_state within update_local_relay_state
  delay(5000);
}
